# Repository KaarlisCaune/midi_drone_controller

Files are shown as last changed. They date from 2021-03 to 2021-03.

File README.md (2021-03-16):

# Arduino MIDI musical drone controller

This is a simple latching MIDI controller. Its "keys" are toggle switches, thus it's meant to play continuos notes or chords.

Also features:
* LEDs for each toggle switch to indicate on / off position
* Switchable low, middle and high octaves

Implementation is extremely simple. Arduino just reads the state of the switches, compares it to its own internal state and sends out noteOn and noteOff MIDI messages. There are some more checks for lower / higher octaves, but that's about it.

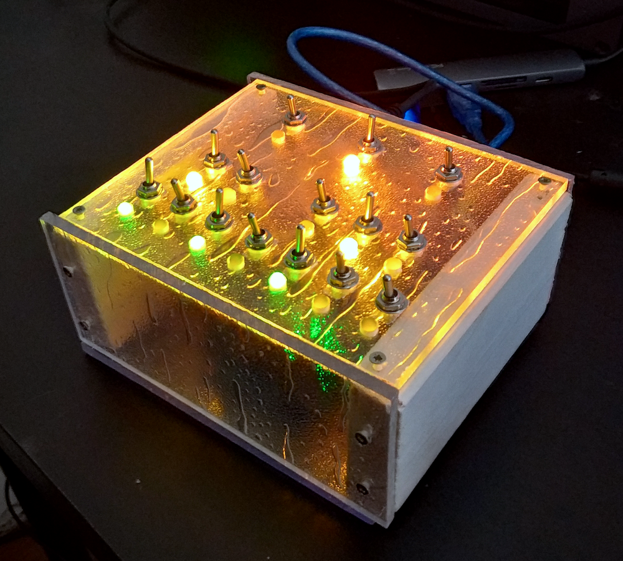
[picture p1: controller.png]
MIDI drone controller


## Wiring

Wiring is simple too, if you use an Arduino Mega - in this case not because of the digital read pin count, but because of max amperage.

The LEDs are not controlled by the Arduino, rather they are directly wired to the toggle switches ground and 5V. 

Since there are 15 LEDs, each possibly pulling about 20mA, this project has the potential of damaging smaller boards - don't attempt that without a safe solution, like using transistors. Mega has multiple 5V / grounds, so when each 5V is connected to max. 5 LEDs, it's pretty safe. Unless you enjoy pink noise, most LED's won't be turned on all the time though.

Part list:

* Arduino Mega
* 15x 2-way toggle switch (three pins, middle ground, ON-ON)
* 15x LEDs
* 17x 220 ohm resistors
* 1x MIDI DIN female connector
* Wires
* Something for your enclosure - I used plexiglass and wood

Wiring for two switches and the MIDI connection:

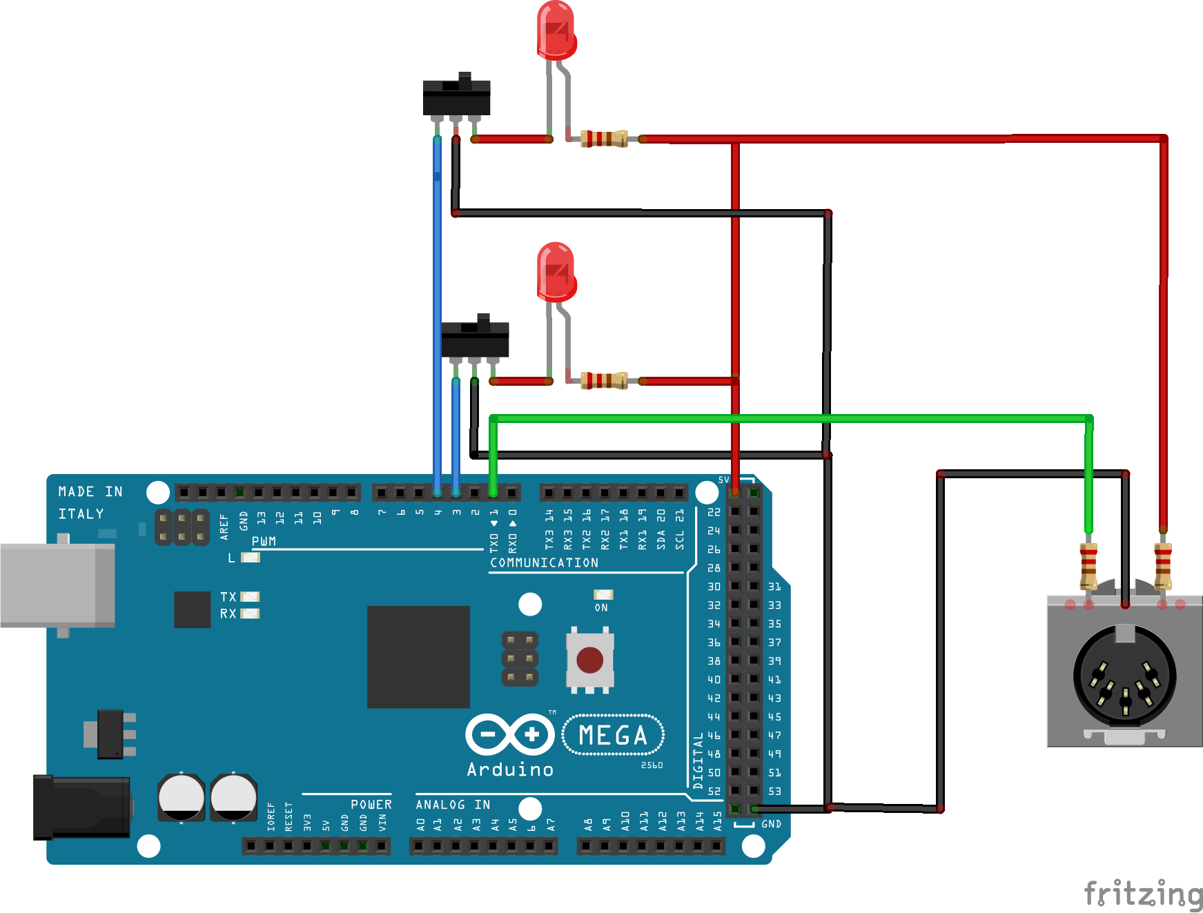
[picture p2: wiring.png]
wiring


## Possible future improvements

It should be relatively easy to add a potentiometer for tempo and turn this into an arpeggiator.

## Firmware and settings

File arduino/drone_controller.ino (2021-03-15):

#define C_PIN 13
#define C_SHARP_PIN 11
#define D_PIN 8
#define D_SHARP_PIN 9
#define E_PIN 7
#define F_PIN 6
#define F_SHARP_PIN 10
#define G_PIN 5
#define G_SHARP_PIN 12
#define A_PIN 4
#define A_SHARP_PIN 2
#define B_PIN 3
#define LOW_OCT_PIN 28
#define MID_OCT_PIN 26
#define HIGH_OCT_PIN 24


int noteON = 144;
int noteOFF = 128;
int defaultVelocity = 100;
int octaveOffset = 24;

bool noteState[] = {
  false, false, false, false, false, false, false, false, false, false,
  false, false, false, false, false, false, false, false, false, false,
  false, false, false, false, false, false, false, false, false, false,
  false, false, false, false, false, false, false, false, false, false,
  false, false, false, false, false, false, false, false, false, false,
  false, false, false, false, false, false, false, false, false, false,
  false, false, false, false, false, false, false, false, false, false,
  false, false, false, false, false, false, false, false, false, false,
  false, false, false, false, false, false, false, false, false, false,
  false, false, false, false, false, false, false, false, false, false 
 };

 class Switch {
  private:
    byte pin;
    byte state;
    byte lastReading;
    int baseNote;
    unsigned long lastDebounceTime = 0;
    unsigned long debounceDelay = 50;
  public:
    Switch(byte pin, int baseNote) {
      this->pin = pin;
      lastReading = LOW;
      this->baseNote = baseNote;
      init();
    }
    void init() {
      pinMode(pin, INPUT_PULLUP);
      update();
    }
    void update() {
      byte newReading = digitalRead(pin);
      
      if (newReading != lastReading) {
        lastDebounceTime = millis();
      }
      if (millis() - lastDebounceTime > debounceDelay) {
        state = newReading;
      }
      lastReading = newReading;
    }
    byte getState() {
      update();
      return state;
    }
    int getNote() {
      return baseNote;
    }
    bool isPressed() {
      return (getState() == HIGH);
    }
};

Switch key_C(C_PIN, 60);
Switch key_C_Sharp(C_SHARP_PIN, 61);
Switch key_D(D_PIN, 62);
Switch key_D_Sharp(D_SHARP_PIN, 63);
Switch key_E(E_PIN, 64);
Switch key_F(F_PIN, 65);
Switch key_F_Sharp(F_SHARP_PIN, 66);
Switch key_G(G_PIN, 67);
Switch key_G_Sharp(G_SHARP_PIN, 68);
Switch key_A(A_PIN, 69);
Switch key_A_Sharp(A_SHARP_PIN, 70);
Switch key_B(B_PIN, 71);
Switch oct_LOW(LOW_OCT_PIN, 0);
Switch oct_MID(MID_OCT_PIN, 0);
Switch oct_HIGH(HIGH_OCT_PIN, 0);

void setup() {
  Serial.begin(31250);
}

void loop() {
  // Look at all note switches
  // C
  if(key_C.isPressed()) {
    switchOnNote(key_C.getNote());
  } else {
    switchOffNote(key_C.getNote());
  }
  // C Sharp
  if(key_C_Sharp.isPressed()) {
    switchOnNote(key_C_Sharp.getNote());
  } else {
    switchOffNote(key_C_Sharp.getNote());
  }
  // D
  if(key_D.isPressed()) {
    switchOnNote(key_D.getNote());
  } else {
    switchOffNote(key_D.getNote());
  }
  // D Sharp
  if(key_D_Sharp.isPressed()) {
    switchOnNote(key_D_Sharp.getNote());
  } else {
    switchOffNote(key_D_Sharp.getNote());
  }
  // E
  if(key_E.isPressed()) {
    switchOnNote(key_E.getNote());
  } else {
    switchOffNote(key_E.getNote());
  }
  // F
  if(key_F.isPressed()) {
    switchOnNote(key_F.getNote());
  } else {
    switchOffNote(key_F.getNote());
  }
  // F Sharp
  if(key_F_Sharp.isPressed()) {
    switchOnNote(key_F_Sharp.getNote());
  } else {
    switchOffNote(key_F_Sharp.getNote());
  }
  // G
  if(key_G.isPressed()) {
    switchOnNote(key_G.getNote());
  } else {
    switchOffNote(key_G.getNote());
  }
  // G Sharp
  if(key_G_Sharp.isPressed()) {
    switchOnNote(key_G_Sharp.getNote());
  } else {
    switchOffNote(key_G_Sharp.getNote());
  }
  // A
  if(key_A.isPressed()) {
    switchOnNote(key_A.getNote());
  } else {
    switchOffNote(key_A.getNote());
  }
  // A Sharp
  if(key_A_Sharp.isPressed()) {
    switchOnNote(key_A_Sharp.getNote());
  } else {
    switchOffNote(key_A_Sharp.getNote());
  }
  // B
  if(key_B.isPressed()) {
    switchOnNote(key_B.getNote());
  } else {
    switchOffNote(key_B.getNote());
  }
}

void switchOnNote(int baseNote) {
  if(oct_MID.isPressed()) {
    if(noteState[baseNote] == false) {
      midiNoteOn(baseNote);
      noteState[baseNote] = true;
    }
  } else {
    if(noteState[baseNote] == true) {
      midiNoteOff(baseNote);
      noteState[baseNote] = false;
    }
  }

  if(oct_LOW.isPressed()) {
    if(noteState[baseNote - octaveOffset] == false) {
      midiNoteOn(baseNote - octaveOffset);
      noteState[baseNote - octaveOffset] = true;
    }
  } else {
    if(noteState[baseNote - octaveOffset] == true) {
      midiNoteOff(baseNote - octaveOffset);
      noteState[baseNote - octaveOffset] = false;
    }
  }

  if(oct_HIGH.isPressed()) {
    if(noteState[baseNote + octaveOffset] == false) {
      midiNoteOn(baseNote + octaveOffset);
      noteState[baseNote + octaveOffset] = true;
    }
  } else {
    if(noteState[baseNote + octaveOffset] == true) {
      midiNoteOff(baseNote + octaveOffset);
      noteState[baseNote + octaveOffset] = false;
    }
  }  
}

void switchOffNote(int baseNote) {
  if(noteState[baseNote] == true) {
    midiNoteOff(baseNote);
    noteState[baseNote] = false;
  }

  if(noteState[baseNote - octaveOffset] == true) {
    midiNoteOff(baseNote - octaveOffset);
    noteState[baseNote - octaveOffset] = false;
  }

  if(noteState[baseNote + octaveOffset] == true) {
    midiNoteOff(baseNote + octaveOffset);
    noteState[baseNote + octaveOffset] = false;
  }
}

void midiNoteOn(int pitch) {
  Serial.write(noteON);
  Serial.write(pitch);
  Serial.write(defaultVelocity);
}

void midiNoteOff(int pitch) {
  Serial.write(noteOFF);
  Serial.write(pitch);
  Serial.write(defaultVelocity);
}
